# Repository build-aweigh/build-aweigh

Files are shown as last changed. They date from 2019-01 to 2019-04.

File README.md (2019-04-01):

Aweigh

Royal College of Art & Imperial College, 2018

States Lee, Sam Iliffe, Keren Zhang, Flora Weil

Aweigh is a non-satellite based navigation alternative, inspired by the polarised vision of insects and ancient celestial navigation. 
This repository contains all the files necessary for building a device. It is currently subject to modifications.

The team is working on increasing the resolution of the device and developing a better distribution platform. 
Most of the files included here are still under construction. Aweigh users are invited to contribute and share their ideas, hacks, and 
improvements in this repository.

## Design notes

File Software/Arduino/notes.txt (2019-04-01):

The team recommends using a Rpi for more accurate trig calculations, which will affect the final result immensely. 
Currently, only one example calculation script for latitude has been included.

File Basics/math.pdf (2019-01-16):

Magnetic Declination: | ∆
Magnetic North: | MN
True North: | TN = MN - ∆

Polarisation Readings:

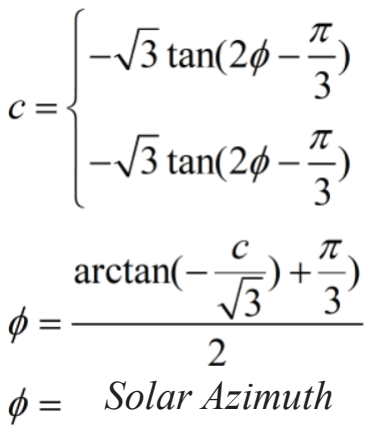
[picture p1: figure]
Solar Azimuth

Solar Azimuth:

Solar Altitude:

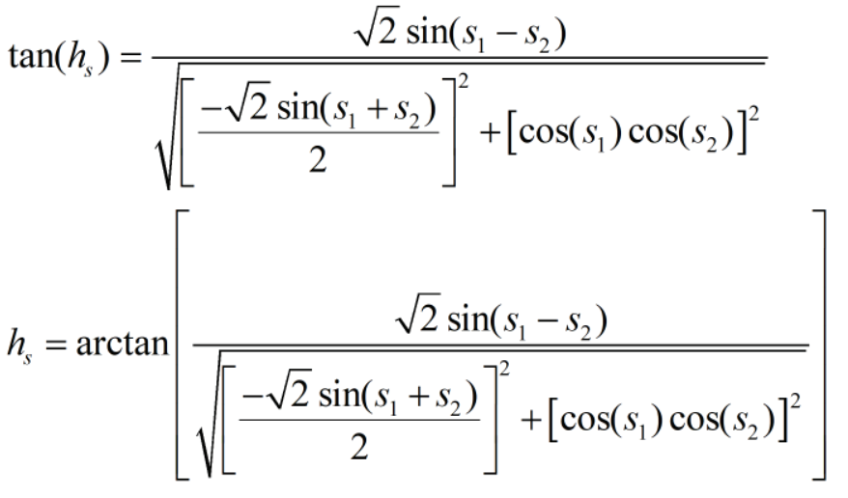
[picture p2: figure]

Solar Altitude

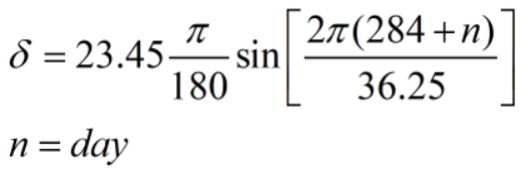
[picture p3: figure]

Declination Angle:

LATITUDE:

Hour Angle:

LONGITUDE:

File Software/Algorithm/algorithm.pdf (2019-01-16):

Magnetic Declination: | ∆
Magnetic North: | MN
True North: | TN = MN - ∆

Polarisation Readings:

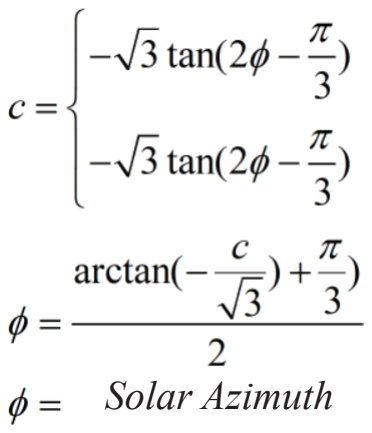
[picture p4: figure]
Solar Azimuth

Solar Azimuth:

Solar Altitude:


Solar Altitude


Declination Angle:

LATITUDE:

Hour Angle:

LONGITUDE:

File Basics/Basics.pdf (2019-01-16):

While Aweigh’s hardware is inspired by insect vision, the algorithm used to calculate latitude and longitude are modelled o ancient navigation techniques and their use of a celestial sphere to position oneself.

In astronomy and celestial navigation, the relationship between the observer’s position and solar angles are:

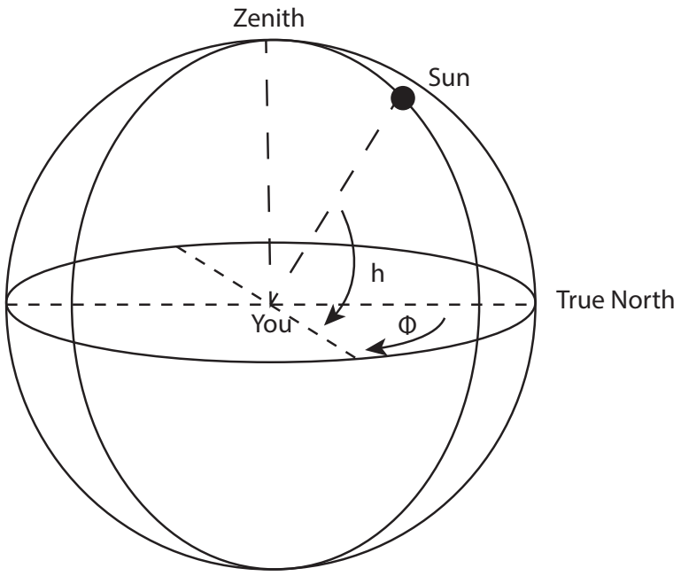
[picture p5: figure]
True North; Sun; Zenith; You

The solar altitude is the angle of the sun relative to the Earth’s horizon. This angle varies based on the time, the day, and is related to latitude. The solar azimuth angle is the horizontal angle that
denes the Sun’s relative direction along the local horizon.

The polarisation analysers allow you to obtain these two angles, which are the two angles essential to determine the “coordinates” of the Sun. Once you are able to locate the Sun, you can locate yourself.

h = solar altitude
Φ = solar azimuth

Algorithm Flow Chart

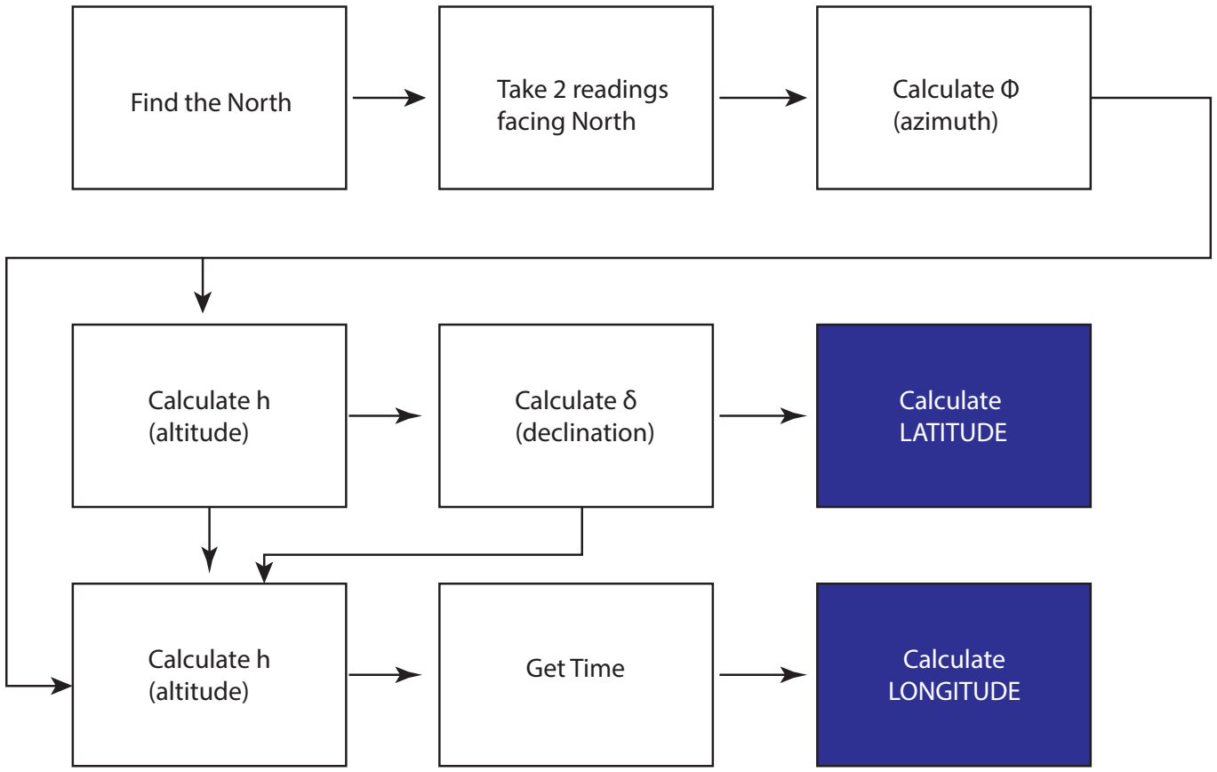
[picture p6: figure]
Find the North; Take 2 readings; facing North; Calculate Φ (azimuth); Calculate h (altitude); Calculate δ (declination); Calculate LATITUDE; Get Time; Calculate; LONGITUDE

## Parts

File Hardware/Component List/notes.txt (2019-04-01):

This bill of materials can be modified depending on the chosen variation of Aweigh. Users are invited to contribute to this repository.

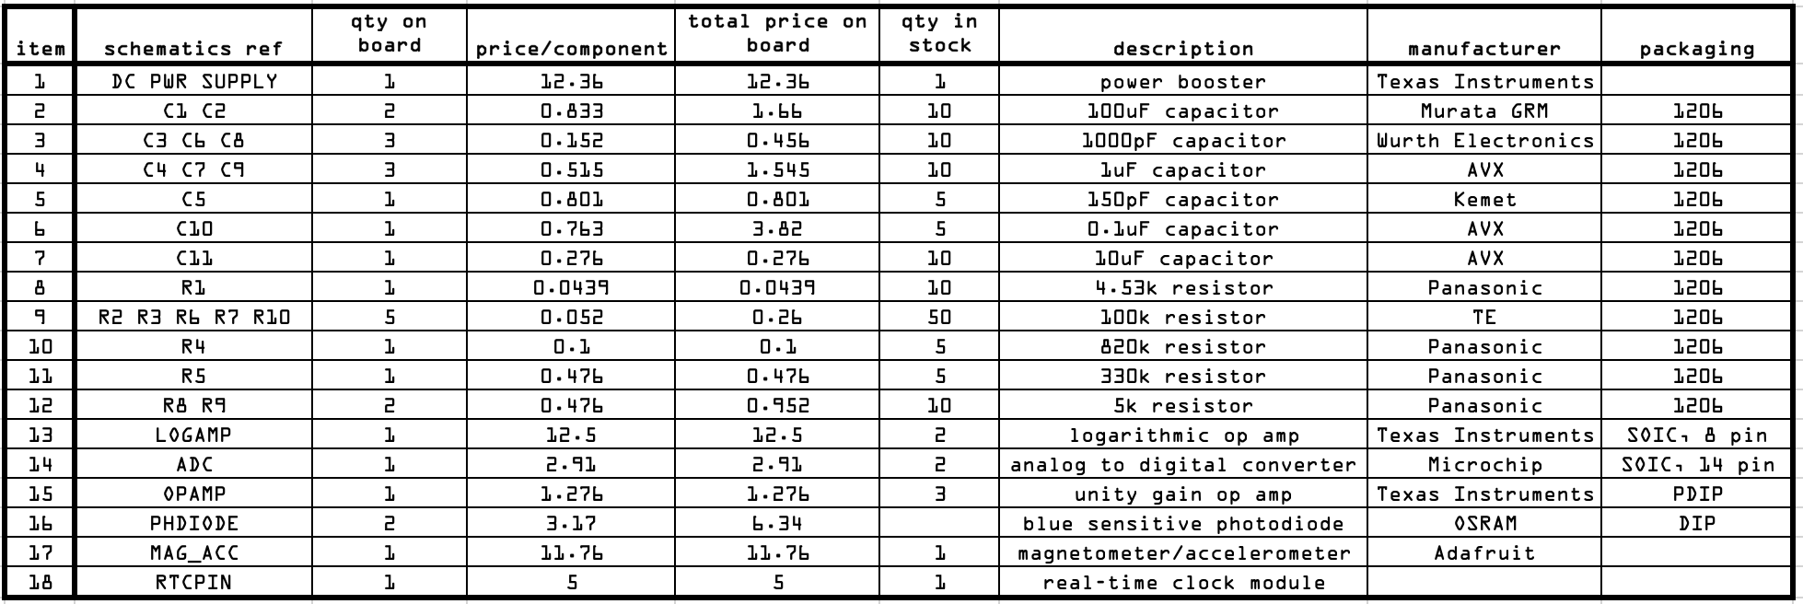
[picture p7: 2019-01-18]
Hardware/Component List/Billofmaterials.png

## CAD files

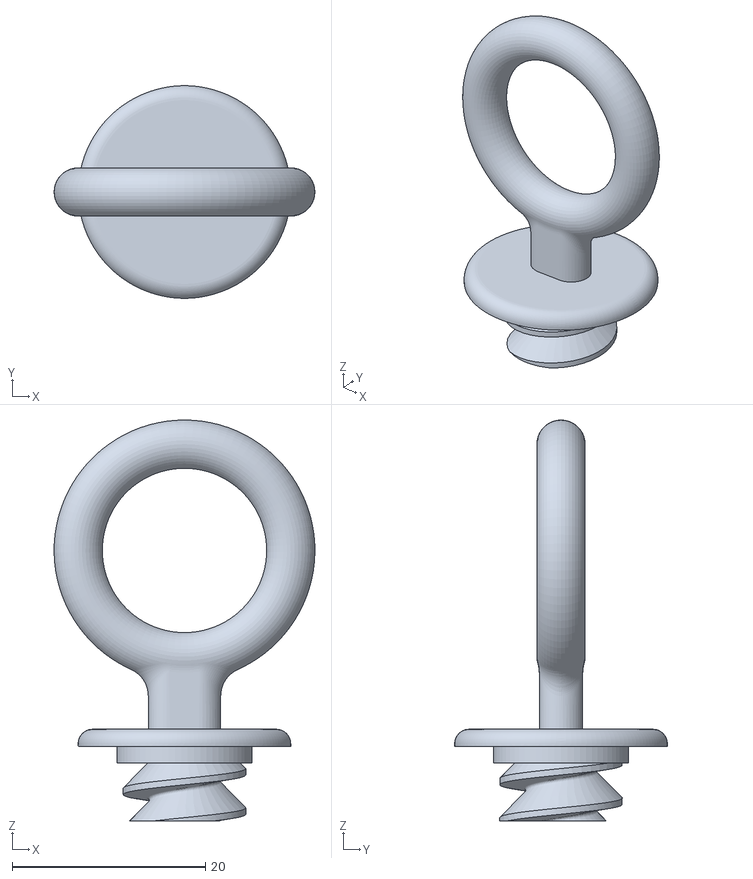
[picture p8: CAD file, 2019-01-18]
Design/3D Printed/final/12.stl
27.0 x 22.0 x 41.5

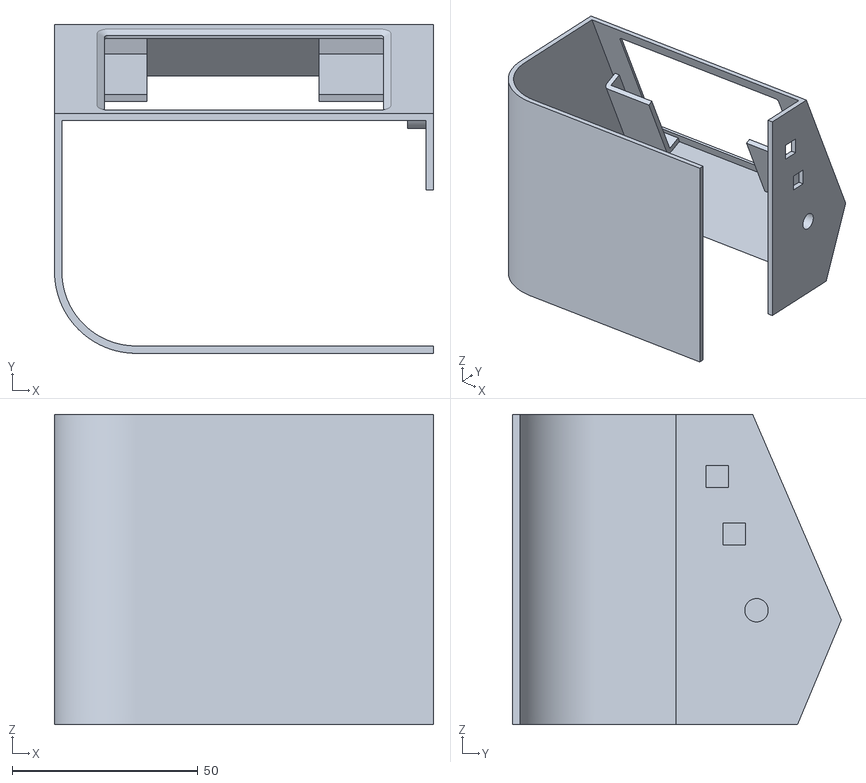
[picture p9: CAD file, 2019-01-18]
Design/3D Printed/functional/23.stl
102.0 x 88.4 x 83.5

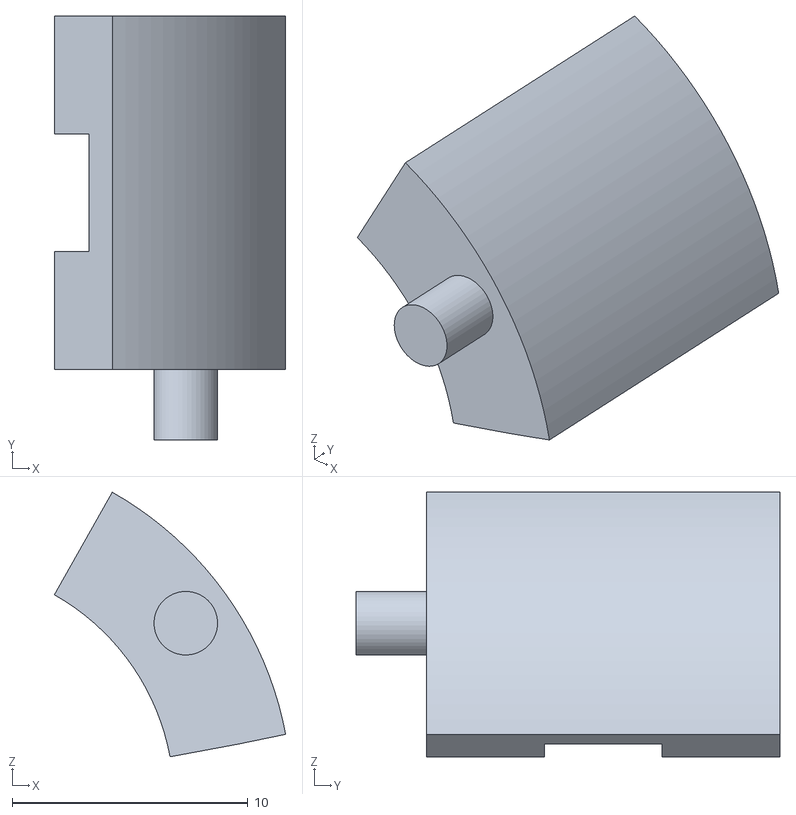
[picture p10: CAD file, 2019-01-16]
Design/3D Printed/stl/SmallPCBfitting.stl
9.82 x 18.0 x 11.2

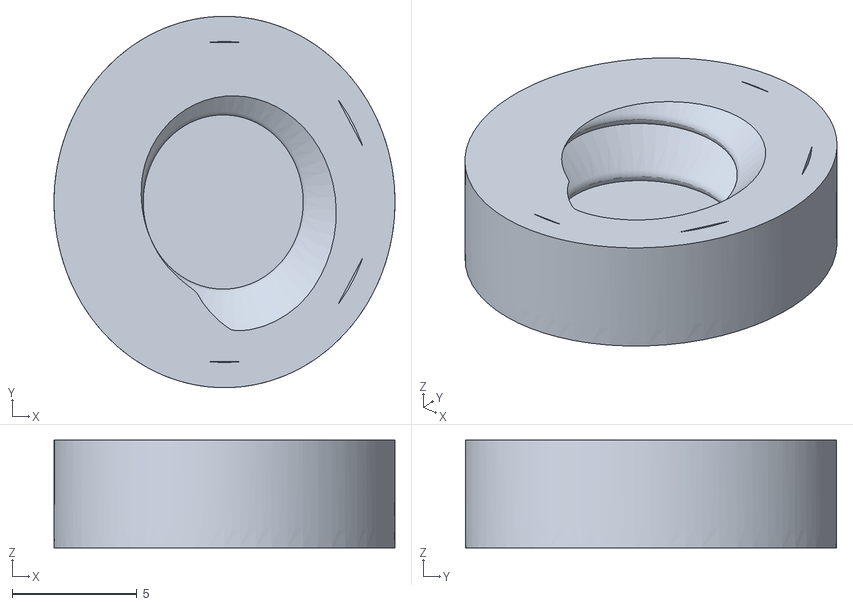
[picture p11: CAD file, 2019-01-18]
Design/3D Printed/final/10.stl
13.7 x 14.9 x 4.31

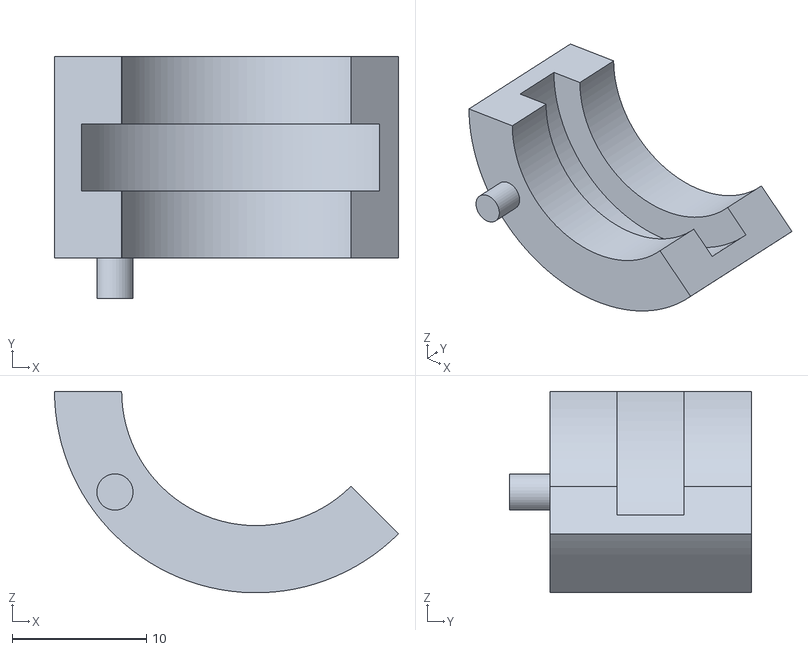
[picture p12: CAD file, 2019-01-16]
Design/3D Printed/stl/LargePCBfitting.stl
25.6 x 18.0 x 15.0

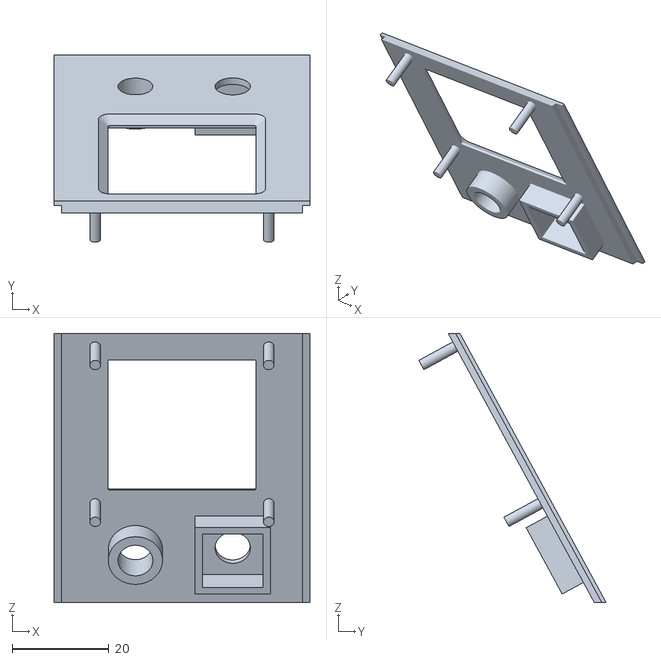
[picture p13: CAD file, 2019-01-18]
Design/3D Printed/final/1.stl
52.9 x 38.8 x 55.7

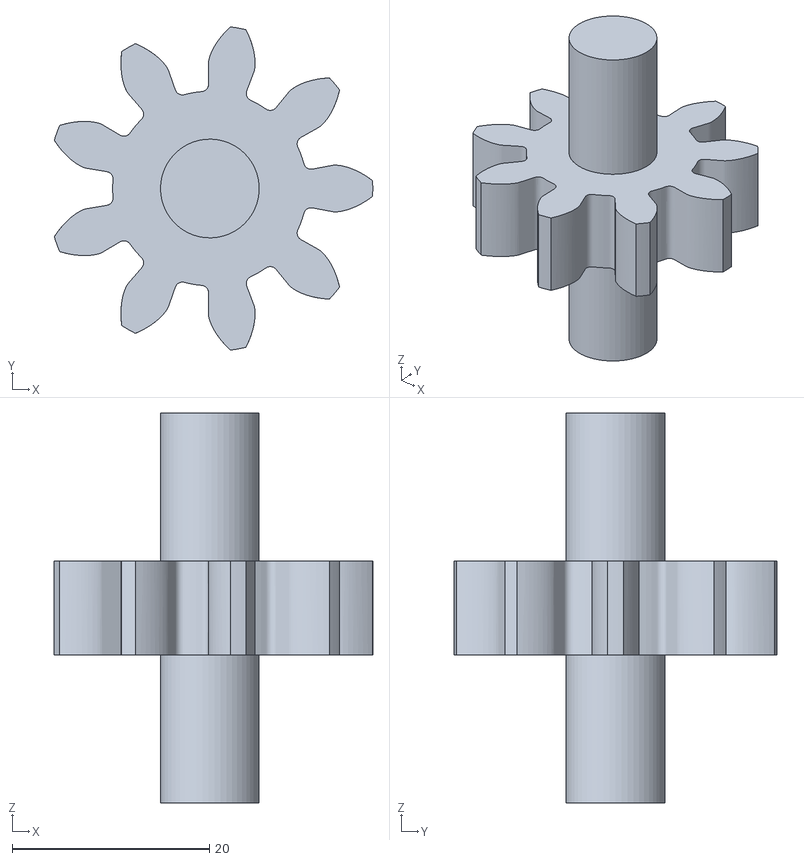
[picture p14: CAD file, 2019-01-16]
Design/3D Printed/stl/Turning gear.stl
32.3 x 32.7 x 39.5

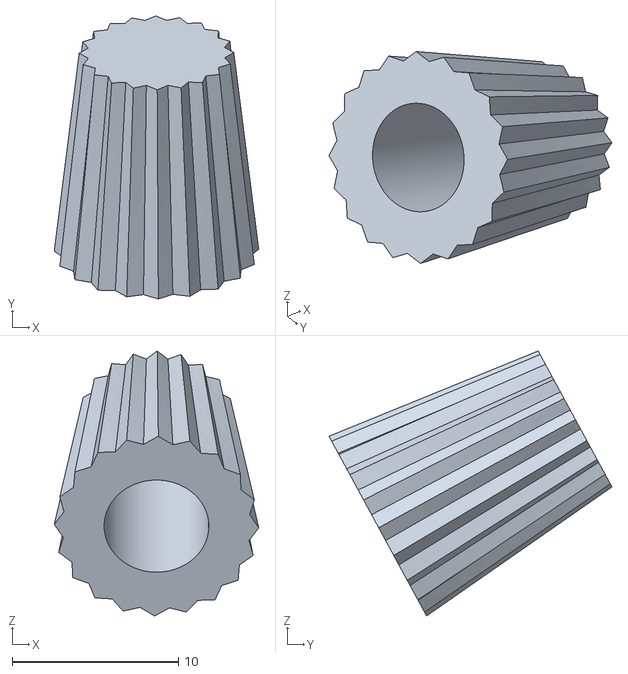
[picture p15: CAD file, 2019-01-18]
Design/3D Printed/final/7.stl
12.3 x 17.0 x 15.9

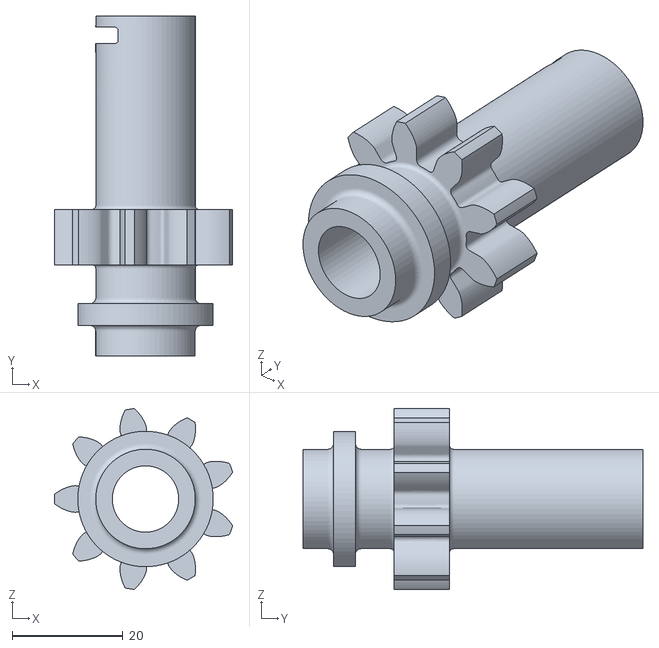
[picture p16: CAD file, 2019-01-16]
Design/3D Printed/stl/Chamber.stl
32.3 x 61.5 x 32.8

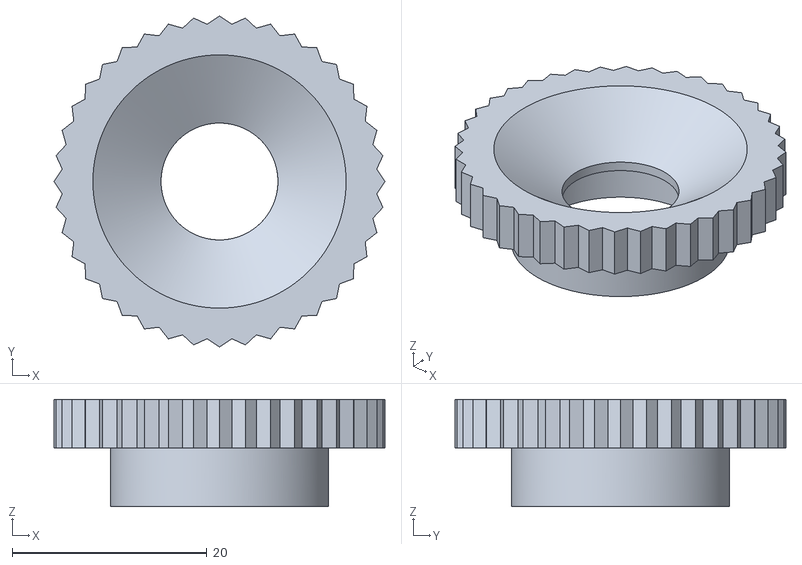
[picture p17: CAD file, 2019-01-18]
Design/3D Printed/final/6.stl
34.0 x 34.0 x 11.0

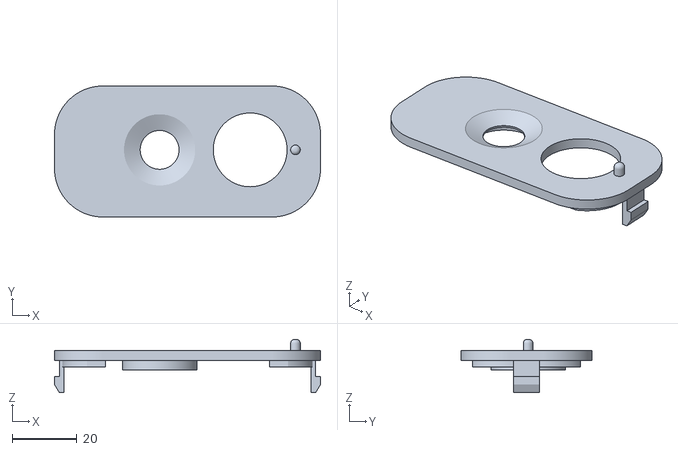
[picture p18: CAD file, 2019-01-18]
Design/3D Printed/final/4.stl
82.2 x 40.5 x 16.5

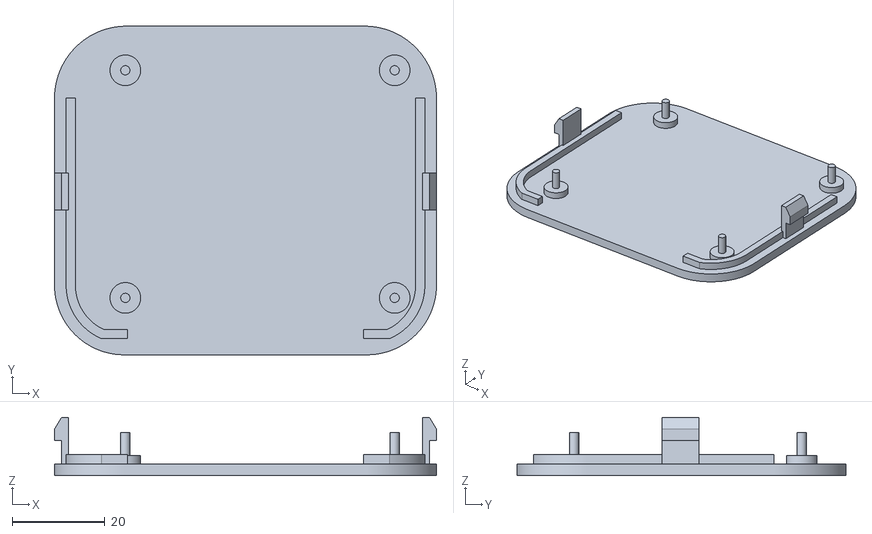
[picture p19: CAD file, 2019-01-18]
Design/3D Printed/final/3.stl
82.2 x 70.8 x 12.5

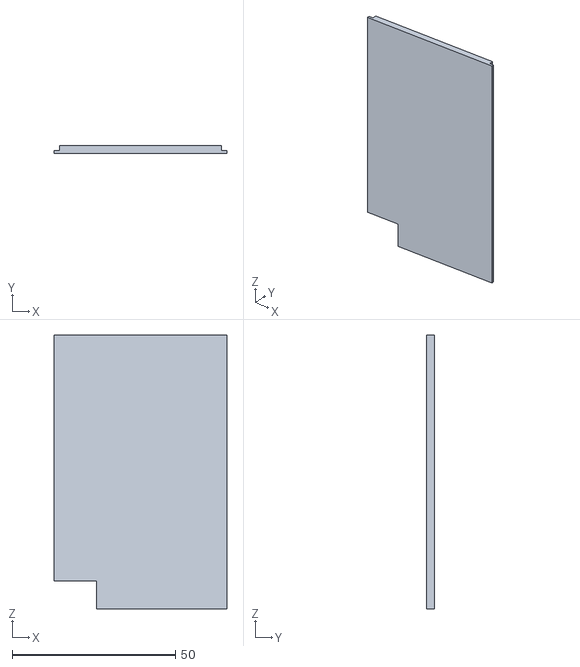
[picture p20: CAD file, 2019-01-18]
Design/3D Printed/final/5.stl
52.9 x 2.45 x 84.0

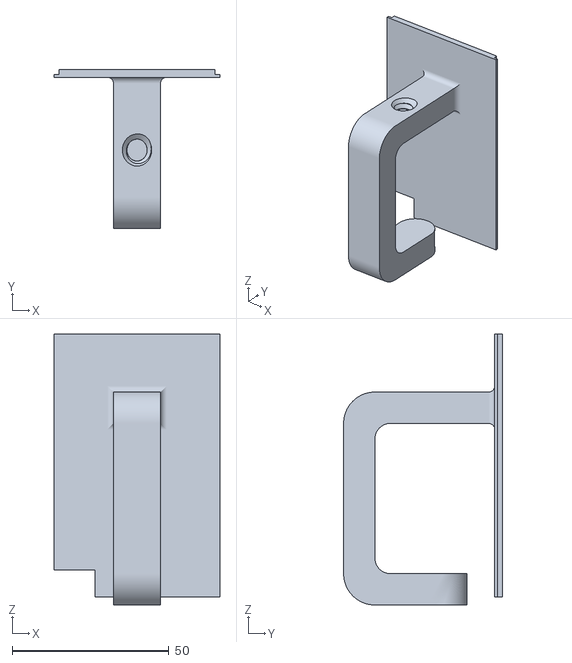
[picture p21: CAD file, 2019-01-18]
Design/3D Printed/final/8.stl
52.9 x 50.7 x 86.5

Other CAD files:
Design/3D Printed/final/9.stl
Design/3D Printed/final/11.stl

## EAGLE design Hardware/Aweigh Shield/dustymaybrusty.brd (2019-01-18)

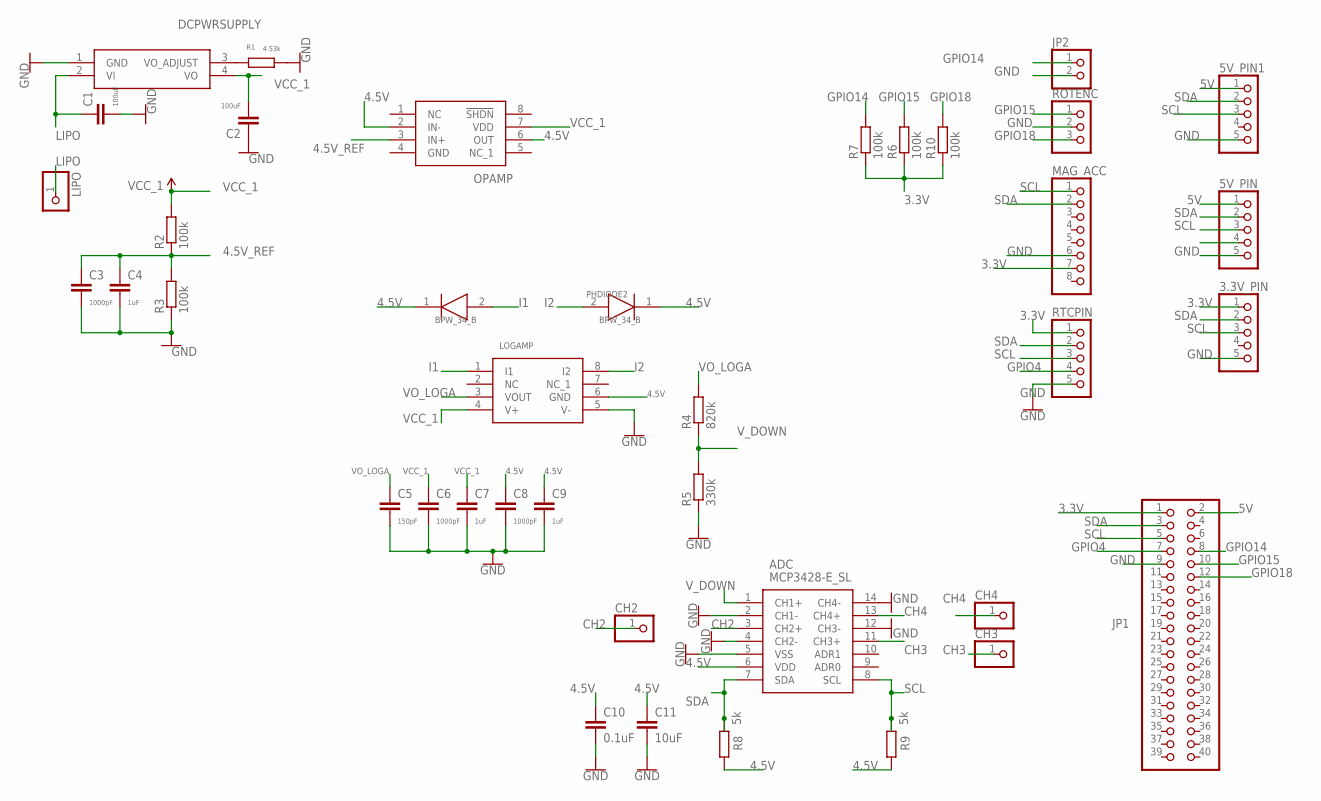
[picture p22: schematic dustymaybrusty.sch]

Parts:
3.3V_PIN, 5V_PIN, 5V_PIN1: PINHD-1X5; 1X05
ADC: MCP3428-E_SL; SOIC127P600X175-14N
C1, C2: 100uF; C1206
C3, C6, C8: 1000pF; C1206
C4, C7, C9: 1uF; C1206
C5: 150pF; C1206
C10: 0.1uF; C1206
C11: 10uF; C1206
CH2, CH3, CH4: PINHD-1X1; 1X01
DCPWRSUPPLY: PTN04050CAD; EUU(R-PDSS-T4)
JP1: PINHD-2X20; 2X20
JP2: PINHD-1X2; 1X02
LIPO: PINHD-1X1; 1X01
LOGAMP: LOG104AID; SOIC127P600X175-8N
MAG_ACC: PINHD-1X8; 1X08
OPAMP: TLV2370IP; DIP794W53P254L959H508Q8N
PHDIODE1, PHDIODE2: BPW_34_B; BPW34B
R1: 4.53k; R1206
R2, R3, R6, R7, R10: 100k; R1206
R4: 820k; R1206
R5: 330k; R1206
R8, R9: 5k; R1206
ROTENC: PINHD-1X3; 1X03
RTCPIN: PINHD-1X5; 1X05

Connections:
3.3V: 3.3V_PIN.1, JP1.1, MAG_ACC.7, R6.1, R7.1, R10.1, RTCPIN.1
4.5V: ADC.6 (VDD), C8.1, C9.1, C10.1, C11.1, LOGAMP.6 (GND), OPAMP.2 (IN-), OPAMP.6 (OUT), PHDIODE1.1 (K), PHDIODE2.1 (K), R8.1, R9.1
4.5V_REF: C3.1, C4.1, OPAMP.3 (IN+), R2.1, R3.2
5V: 5V_PIN.1, 5V_PIN1.1, JP1.2
CH2: ADC.3 (CH2+), CH2.1
CH3: ADC.11 (CH3+), CH3.1
CH4: ADC.13 (CH4+), CH4.1
GND: 3.3V_PIN.5, 5V_PIN.5, 5V_PIN1.5, ADC.2 (CH1-), ADC.4 (CH2-), ADC.5 (VSS), ADC.12 (CH3-), ADC.14 (CH4-), C1.2, C2.1, C3.2, C4.2, C5.2, C6.2, C7.2, C8.2, C9.2, C10.2, C11.2, DCPWRSUPPLY.1 (GND), JP1.9, JP2.2, LOGAMP.5 (V-), MAG_ACC.6, OPAMP.4 (GND), R1.1, R3.1, R5.1, ROTENC.2, RTCPIN.5
GPIO4: JP1.7, RTCPIN.4
GPIO14: JP1.8, JP2.1, R7.2
GPIO15: JP1.10, R6.2, ROTENC.1
GPIO18: JP1.12, R10.2, ROTENC.3
I1: LOGAMP.1 (I1), PHDIODE1.2 (A)
I2: LOGAMP.8 (I2), PHDIODE2.2 (A)
LIPO: C1.1, DCPWRSUPPLY.2 (VI), LIPO.1
unnamed: DCPWRSUPPLY.3 (VO_ADJUST), R1.2
SCL: 3.3V_PIN.3, 5V_PIN.3, 5V_PIN1.3, ADC.8 (SCL), JP1.5, MAG_ACC.1, R9.2, RTCPIN.3
SDA: 3.3V_PIN.2, 5V_PIN.2, 5V_PIN1.2, ADC.7 (SDA), JP1.3, MAG_ACC.2, R8.2, RTCPIN.2
VCC_1: C2.2, C6.1, C7.1, DCPWRSUPPLY.4 (VO), LOGAMP.4 (V+), OPAMP.7 (VDD), R2.2
VO_LOGA: C5.1, LOGAMP.3 (VOUT), R4.2
V_DOWN: ADC.1 (CH1+), R4.1, R5.2

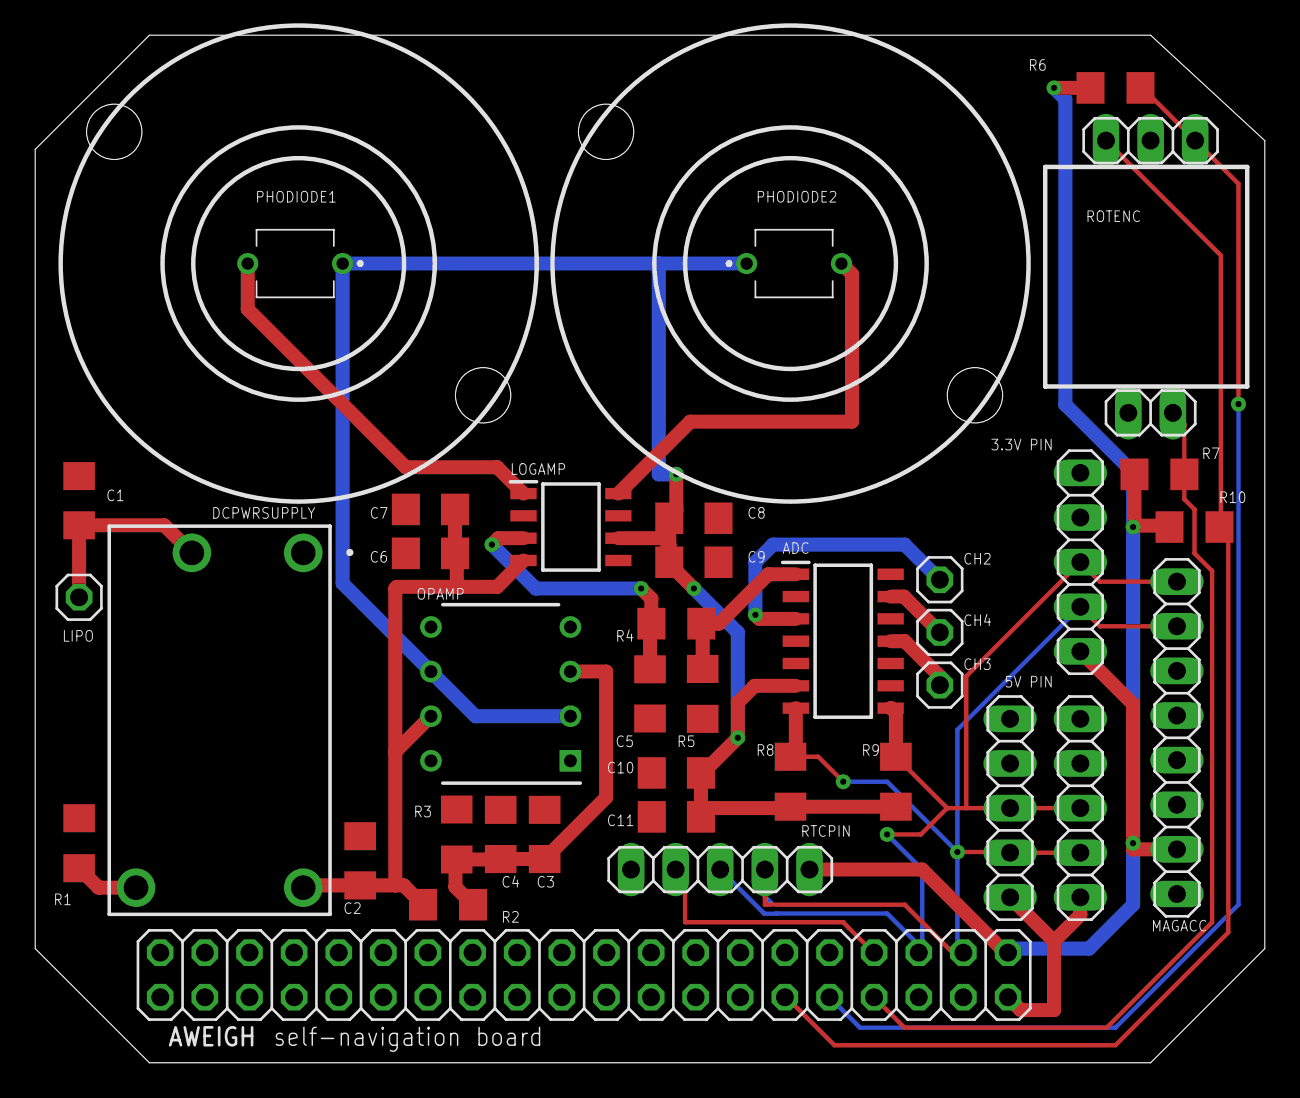
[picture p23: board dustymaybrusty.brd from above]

Board: 2 copper layers, 70.0 x 58.5 mm, 39 parts (0 on the bottom side), 21 nets.

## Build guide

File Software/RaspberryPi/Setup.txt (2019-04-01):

Things to set up before running latitude.py:

- I2c: 
Inter-intergrated circuit (i2c) is a protocol for communicating with low-speed peripherals.
On the Rpi, you can connect up to two devices to the SCL and SDA master pins (GPIO3 and GPIO5).
Make sure the connections are made in parallel and that each sensor is using a different address. 
ADC:
Mag-sensor:

- Magnetometer:
Clone the following repository for the QMC5883L magnetometer: https://github.com/RigacciOrg/py-qmc5883l

- Analog to Digital Converter:
Install necessary drivers: https://learn.adafruit.com/raspberry-pi-analog-to-digital-converters/ads1015-slash-ads1115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 
Commands are:
sudo apt-get update
sudo apt-get install build-essential python-dev python-smbus python-pip
sudo pip install adafruit-ads1x15

Other components, depending on the user's preferences, will need to be set up as well. All of the team's device versions have been
implemented with Adafruit sensors or components, which are linked to detailed installation instructions. 
https://www.adafruit.com/categories

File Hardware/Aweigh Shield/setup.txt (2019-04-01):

This PCB design was based on polarisation angle reading research papers. The additional components (magnetometer, RTC, etc.) can be
changed for more accuracy. Currently, the team is still trying to develop a way to robustly calculate position, while using cheap resources.

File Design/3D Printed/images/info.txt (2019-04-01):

This folder contains some 3D printed variations of Aweigh - not all options that have been tested are included.

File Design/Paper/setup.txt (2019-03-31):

These files are subject to modifications and are not final designs. Some of them have been used for initial versions of Aweigh.

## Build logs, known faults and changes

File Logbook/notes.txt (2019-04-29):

The logbook is ongoing modifications. Current version is nonetheless available for free downloads.

If the pdf is too large to be displayed as a PNG on Github, right click on the link and open it in a new tab. You should then be able to download the file there.

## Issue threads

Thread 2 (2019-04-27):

[suggestion] Investigate MicroPython/CircuitPython support

ntoll, 2019-04-27:
Cool hack!

My first impression was it would be a great educational project for teens interested in technology. To that end, perhaps making it work with CircuitPython on, say, Adafruit boards would get your work in front of a bunch of friendly / receptive hardware hackers and teachers.

s-light, 2019-05-03:
@ntoll that also was one of the first ideas that came to my mind as i found the project..
i had only a short look at the [code](https://github.com/build-aweigh/build-aweigh/blob/master/Software/RaspberryPi/Latitude_Longitude.py#L43)
this should be very easy to port to CircuitPython (CP).. but i have the feeling that this code is not really all that is needed?!

would be good to do a restructuring first - move the calculations to a sub-module/file with a function or class api. (don't know for sure if internal states are needed)
best case → this works in both python3 on PI and CP

for the sensor IO we are at the right time / on a good way to have a single API for this -
have a look at [Adafruit Blinka](https://github.com/adafruit/Adafruit_Blinka/tree/master/src/adafruit_blinka/board) it supports a bunch of platforms..
:-)

i think one of the [M4 / ATSAMD51 Boards](https://www.adafruit.com/category/952)
should have enough power to do this kind of thing..

if i find time (the big challenge ;-)) i will try this..
(seems i have almost all the components on the shelf..)
but if somebody else is doing it, i bet he/she will be faster ;-)

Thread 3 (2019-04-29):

Servo positioning code missing.

hamsternz, 2019-04-29:
In latitude_longitude.py, in the main loop this is called to move the filter:

 p.ChangeDutyCycle(7.5)

Shouldn't this also be called before the first reading is taken?

 p.ChangeDutyCycle(3.0)

It isn't a problem on the first pass, as the servo is initialized that way, but on the second pass and subsequent passes the filter won't be moved.

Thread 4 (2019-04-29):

What kind of precision to expect from such system?

X-Ryl669, 2019-04-29:
There's no precision given anywhere on the website.
Can you tell us what precision (error) you'd get with such system (assuming your ADC choice?)

s-light, 2019-05-03:
just some theoretical info i found on page 16 in the [Logbook](https://github.com/build-aweigh/build-aweigh/blob/master/Logbook/Aweigh%20book.pdf):
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

> Looking   back   in   history   we   found   that   the   sextant   was   a   perfectly   suitable   method   of   navigation    for    maritime    navigators,    and    is    still  used  as  a  backup  to  GNSS  today  (16).  The  accuracy  of  some  of  these  sextants  was  in  the  range   of   around   370   meters,   which   was   also   about  the  same  level  of  accuracy  that  GPS  had  before the 21st century (17).

its a first clue in what range we can think.. (as the concept of the sextant is used in the device)

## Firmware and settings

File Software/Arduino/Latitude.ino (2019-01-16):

#include <Wire.h>
#include <Adafruit_ADS1015.h>
#include <math.h>  

Adafruit_ADS1115 ads(0x48);
float Voltage=0.0;
float s1[10];
float s2[10];
float s1_max;
float s2_max;
float a=0.0;
float b=0.0;
float c=0.0;
float a2=0.0;
float b2=0.0;
float c2=0.0;
float phi=0.0;
float lastTimer = millis();
int StopitHere = 0;
float latitude = 0.0;
int delta;

void setup() {
  Serial.begin(9600);
  ads.begin();
}

void loop() {

  if (StopitHere >=1){
    if (millis()-lastTimer)>1000){
        //Data acquisition
      int16_t adc0;  // we read from the ADC, we have a sixteen bit integer as a result
      adc0 = ads.readADC_SingleEnded(0);  
      //Turn the sensors
      //Store in s1,s2
      lastTimer = millis(); //reset
    }
  }
  
  //Find max value for s1, s2

  //Get declination angle from database

  //Latitude output conversion
    //apply sigmoid function
    a = 1/((pow(10, s1_max)+1);
    a2 = 1/((pow(10, s2_max)+1);
    //apply trigonometric function
    b = 1-2*a
    b2 = 1-2*a2
    //get rid of degree of polarisation
    c = (a - a2)/(abs(a)-abs(a2))
    //calculate hour angle
    phi = 2*((pi/3)+artan(c/sqrt(3)));
    //calculate latitude with delta and phi
    latitude = acos(cos(phi)/sqrt(sin(delta)*sin(delta)+cos(phi)*cos(phi)*cos(delta)*cos(delta)))+atan((cos(phi)*cos(delta))/sin(delta))

  //Output to serial
  Serial.println(latitude);  
    
  delay(500);
  }

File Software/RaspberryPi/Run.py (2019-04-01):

import RPi.GPIO as GPIO
import time
import os

#adjust for where your switch is connected
buttonPin = 17
GPIO.setmode(GPIO.BCM)
GPIO.setup(buttonPin,GPIO.IN)

while True:
  #assuming the script to call is long enough we can ignore bouncing
  if (GPIO.input(buttonPin)):
    #this is the script that will be called (as root)
    os.system("python /home/pi/Latitude_Longitude.py")

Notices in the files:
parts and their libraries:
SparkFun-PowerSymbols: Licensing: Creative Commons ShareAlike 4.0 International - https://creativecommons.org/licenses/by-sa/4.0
